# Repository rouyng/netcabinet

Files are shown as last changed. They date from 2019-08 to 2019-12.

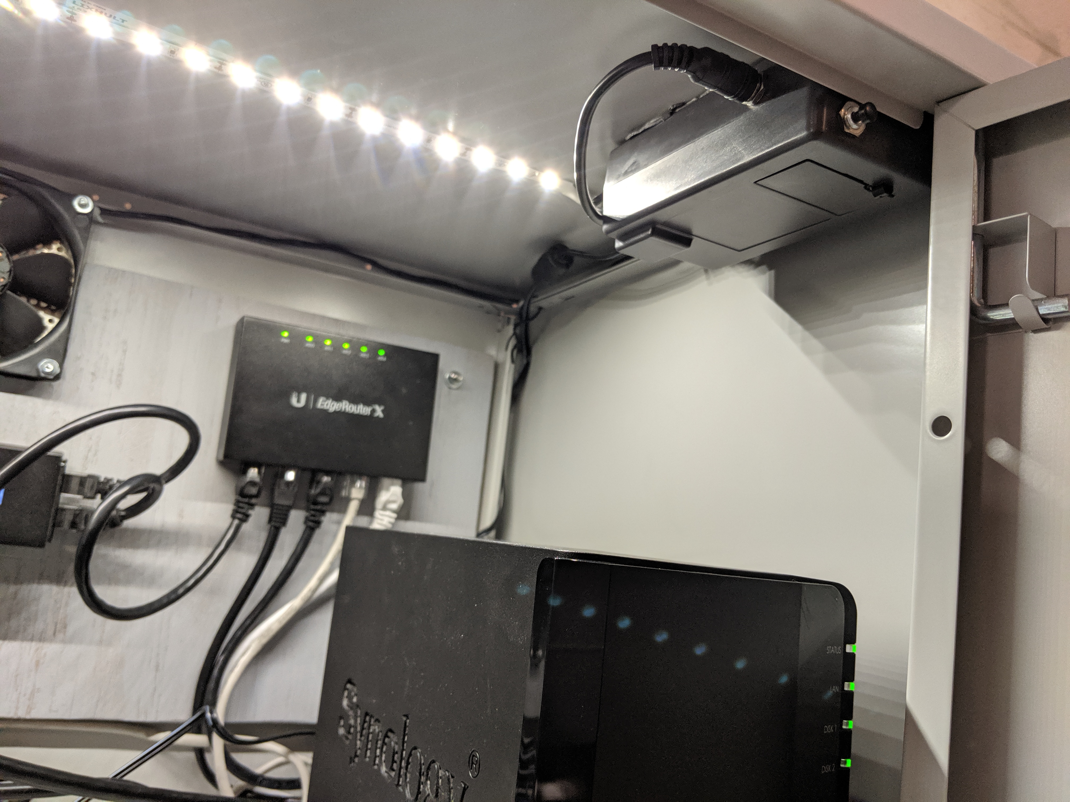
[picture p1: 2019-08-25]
doc/netcabinet photo 3.jpg

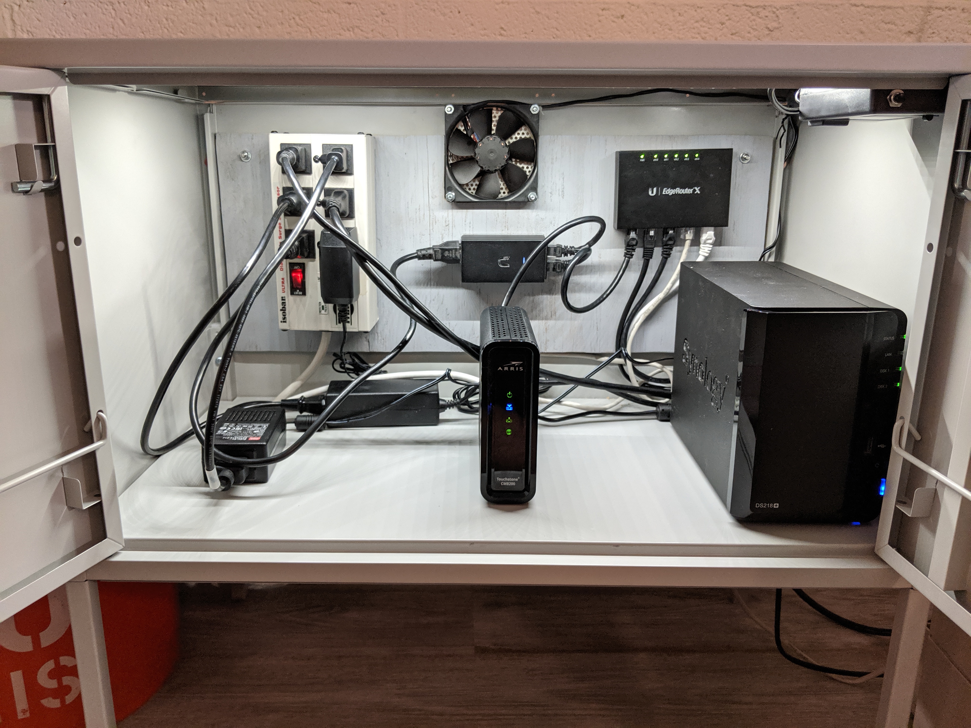
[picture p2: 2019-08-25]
doc/netcabinet photo 2.jpg

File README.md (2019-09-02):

# Networking Cabinet

Arduino sketch and design reference for my networking cabinet with integrated fan and LED lighting.

## Overview

An Arduino-powered controller that regulates temperature using a 12V fan controller by a PID loop fed with data from a TMP36 temperature sensor. Uses [Brett Beauregard's PID library for Arduino.](https://github.com/br3ttb/Arduino-PID-Library/)

A pushbutton switch detects when the cabinet door is open/closed. When door is open, fan is turned off and LED light strip turns on. When door is closed, LED strip is turned off and PID control of the fan is enabled.

Everything is built into a modified IKEA Lixhult cabinet. The cabinet contains a surge protector, Synology NAS, Ubiquiti Edgerouter X, PoE injector and a cable modem. Planning to add a Unifi US-8-60W switch.

## Hardware
See /doc for images and fritzing file.

- Ardunio UNO
- Generic pushbutton switch
- TMP36 temperature sensor
- Sparkfun Ardumoto shield
- 90mm muffin fan, 12 VDC
- approx 1' length Hitlights L2012V-401-1030-U 4100K LED light strip. 12 VDC, 2.8 Watts/ft
- MEAN WELL GST25A12-P1J Desktop AC Adapter, 120VAC to 12VDC 2A

## Logging
The Python script found at `log/cabinetlog.py` is designed to log data from the USB serial connection of the Arduino and generate a CSV file. The data logged by the CSV file can be adjusted by changing which variables are printed to the serial connection within `fanctl.ino`.

Tested using Python 3.5.1 running on a Synology DS218+. It may be necessary to run `sudo stty -F /dev/ttyACM0 9600 tostop` (replacing `/dev/ttyACM0` with whatever serial port the Arduino is located  at) in order to prevent other processes from writing to the serial connection and resetting the Arduino.

## TODO
- PID loop tuning based on data

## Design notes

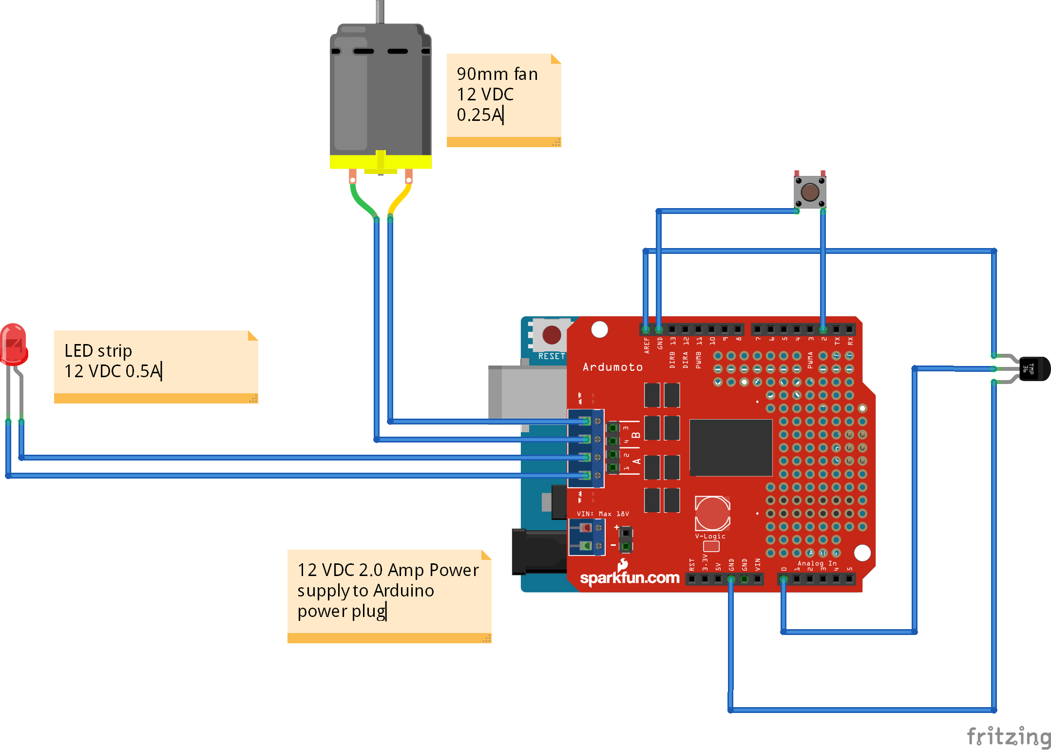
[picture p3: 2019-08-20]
doc/netcabinet layout.png

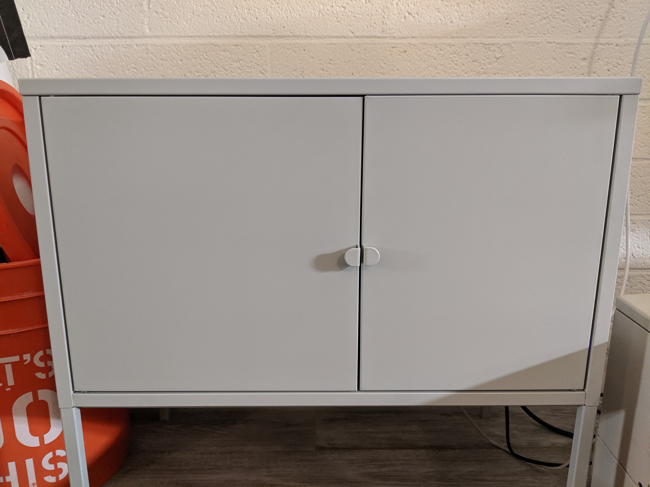
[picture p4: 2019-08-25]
doc/netcabinet photo 1.jpg

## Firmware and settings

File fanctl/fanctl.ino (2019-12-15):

#include <PID_v1.h>

byte PWMA = 3; // PWM control (speed) for fan motor on Ardumoto shield
byte PWMB = 11; // PWM control (brightness) for LED strip on Ardumoto shield
byte DIRA = 12; // Polarity control for fan motor on Ardumoto shield
byte DIRB = 13; // Polarity control for LED strip on Ardumoto shield
byte doorPin = 2; // digital input pin for door switch
int sensorPin = A0; // Analog input pin for TMP36 sensor
int sensorVal = 0;
float tempF = 0;
int ledBright = 0; // LED brightness PWM value


// Loop timing variables
unsigned long timeStep = 5; // Time interval for LED brightness ramping (longer == more gradual ramp)
unsigned long logInterval = 1000; // Time interval for sending logging data over serial connection
unsigned long currentTime = millis();
unsigned long lastTime1 = currentTime; 
unsigned long lastTime2 = currentTime;
unsigned long lastTime3 = currentTime;

// PID variables
double Input, Output;
double Kp=3, Ki=0.2, Kd=1; // Change these values to tune PID loop
double Setpoint = 85; // PID setpoint temp in degrees Fahrenheit
PID myPID(&Input, &Output, &Setpoint, Kp, Ki, Kd, DIRECT);

void setup()
{
  setupArdumoto(); // Set all pins as outputs
  Serial.begin(9600); // serial output for debugging
  pinMode(doorPin, INPUT_PULLUP); //As switch is directly attached to pins, we use INPUT_PULLUP to activate the Arduino's internal pullup resistor
  myPID.SetMode(AUTOMATIC);
  myPID.SetOutputLimits(150, 255); // Set minimum/maximum PWM values for controlling fan speed. Min value should be high enough than the fan will not stall
  myPID.SetControllerDirection(REVERSE);
}

void loop()
{
  if (digitalRead(doorPin) == HIGH) //Fan control will only turn on if door is closed
  	{
  		if (checkTemp() > (Setpoint - 0.25)) {
  			Input = checkTemp();
    		myPID.Compute();
    		analogWrite(PWMA, Output);
  		}
  		else {
  		   analogWrite(PWMA, 0);
  		}	
    ledOff();
 	 }
  else 
  {
    analogWrite(PWMA, 0);
    ledOn();	
  }
  serialLog();
}

// setupArdumoto shield by initializing all pins
void setupArdumoto()
{
  // All pins should be setup as outputs:
  pinMode(PWMA, OUTPUT);
  pinMode(DIRA, OUTPUT);
  pinMode(PWMB, OUTPUT);
  pinMode(DIRB, OUTPUT);

  // Initialize all pins as low:
  digitalWrite(PWMA, LOW);
  digitalWrite(PWMB, LOW);
  digitalWrite(DIRA, LOW);
  digitalWrite(DIRB, LOW);
}

// return temperature in Fahrenheit from TMP36 sensor
float checkTemp()
{
	int sensorVal = analogRead(sensorPin);
	float voltage = sensorVal * 5.0;
 	voltage /= 1024.0; 
 	tempF = (((voltage - 0.5) * 100)* 9.0 / 5.0) + 32.0;
 	return tempF;
}

// turn LED strip on with a smooth fade by raising the PWM value
void ledOn()
{
  while (ledBright < 255)
    {
      if(millis() > lastTime1 + timeStep)
      {
		lastTime1 = millis();
		ledBright = ledBright + 1;
		analogWrite(PWMB, ledBright);
      }
    }
}

// turn LED strip off with a smooth fade by lowering the PWM value
void ledOff()
{
  unsigned long currentTime = millis();
  while (ledBright > 0)
    {
      if(millis() > lastTime2 + timeStep)
      {
		lastTime2 = millis();
		ledBright = ledBright - 1;
		analogWrite(PWMB, ledBright);
      }
    }
}

// Send log data over serial connection
void serialLog()
{
  String doorStatus = "";
  	if(millis() > lastTime3 + logInterval)
	  {
	    lastTime3 = millis();

	    // Set doorStatus varible based on whether door switch is open or closed
	    if(digitalRead(doorPin) == HIGH)
	    {
	      doorStatus = "CLOSED";
	    }
	    else
	    {
	      doorStatus = "OPEN";
	    }
	    //Print log data over serial, comma-separated
	    Serial.print(Output); //PID fan control speed
	    Serial.print(", ");
	    Serial.print(tempF); // Temperature
	    Serial.print(", ");
	    Serial.print(doorStatus); // Door open or closed
	    Serial.print(", ");
	    Serial.print(ledBright); // LED brightness
	    Serial.print(", ");
	    Serial.print(lastTime3 / 1000); //print time since program start in seconds
	    Serial.println(", ");
	  }
}

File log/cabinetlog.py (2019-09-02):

import serial
import datetime
import csv

# open serial connection, /dev/ttyACM0 should be changed to the serial port where the Arduino is connected
ser = serial.Serial('/dev/ttyACM0', 9600)

# script will run until it receives a keyboard interrupt or is otherwise killed
while True:
    try:
        ser_bytes = ser.readline()                                      # read one line from serial connection
        decoded_bytes = ser_bytes[0:len(ser_bytes) - 3].decode("utf-8") # decode raw input to UTF-8 encoding, slice string to remove trailing characters
        currtime = datetime.datetime.now()                              # get current time
        # create or append to an existing csv file
        with open('{}-cabinetlog.csv'.format(currtime.strftime("%m.%d.%y")), 'a') as f:
            # set up csv file parameters, no quoting because the serial output is already comma delimited
            writer = csv.writer(f, delimiter=",", escapechar=' ', quoting=csv.QUOTE_NONE)
            # write current date/time and one line of serial output to a row
            writer.writerow([currtime.strftime("%c"), decoded_bytes])
    # a tidy-looking exception for keyboard interrupts, because this script will likely be keyboard-interrupted a lot!
    except KeyboardInterrupt:
        print('Keyboard interrupt!')
        break

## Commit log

2019-08-19 upload arduino sketch
2019-08-20 Update fanctl.ino
    Add minimum speed limit to PID control, prevent PID fan control from running below 79 degrees
    [fanctl.ino]
2019-08-20 add fritzing files
    add .fzz file, add layout image
    [netcabinet.fzz]
2019-08-20 add doc folder
    [netcabinet.fzz]
2019-08-23 Update README.md
    link to PID library
2019-09-02 create python script for logging arduino data to CSV file
2019-12-15 adjust temp setpoint and fan minimum speed
2019-12-15 change temp threshold calculation for turning on PID control
